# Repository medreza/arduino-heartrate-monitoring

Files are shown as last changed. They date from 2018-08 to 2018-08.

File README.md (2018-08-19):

# arduino-heartrate-monitoring

Heartrate monitoring based on photodiode sensor and Arduino. Uses Processing for user interface.

This was mini project for Electronics Instrumentation 2014 class in FMIPA Universitas Gadjah Mada. 

The video of this project can be seen on:
https://www.youtube.com/watch?v=Lp79tmzNe8U

### Some pics
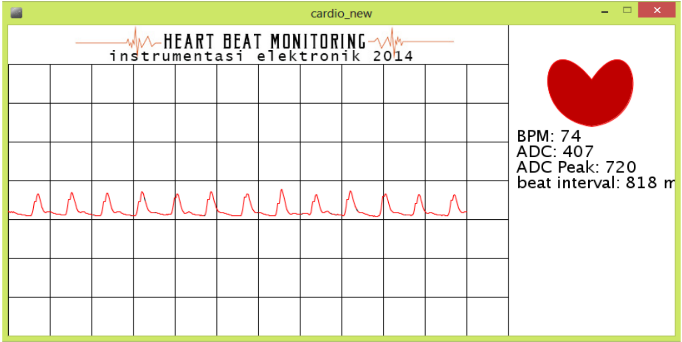
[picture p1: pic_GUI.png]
User interface using Processing IDE


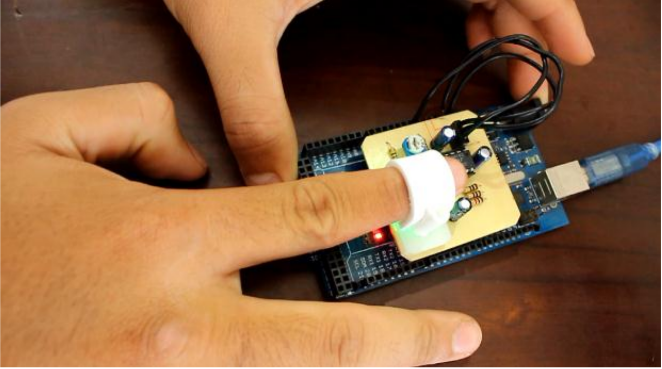
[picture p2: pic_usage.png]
Arduino with photodiode sensor


### Credit goes to team members
- Aditya Riska Putra
- Ahmed Reza Rafsanzani
- Ryan Eko Saputro
- Zainul Anam

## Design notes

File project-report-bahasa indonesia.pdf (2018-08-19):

## LAPORAN FINAL PROJECT

PENGUKURAN DETAK JANTUNG MENGGUNAKAN ARDUINO DAN

PROCESSING IDE

Mata Kuliah Instrumentasi Elektronik

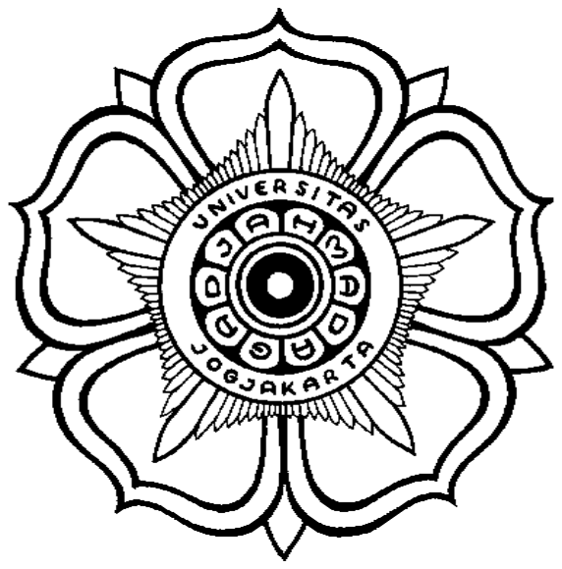
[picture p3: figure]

Disusun oleh:

ADITYA RISKA PUTRA | (12/331108/PA/14450)
AHMED REZA RAFSANZANI | (12/334832/PA/15030)
RYAN EKO SAPUTRO | (12/331380/PA/14638)
ZAINUL ANAM | (12/331361/PA/14624)

PROGRAM STUDI ELEKTRONIKA DAN INSTRUMENTASI

JURUSAN ILMU KOMPUTER DAN ELEKTRONIKA

FAKULTAS MATEMATIKA DAN ILMU PENGETAHUAN ALAM

UNIVERSITAS GADJAH MADA

YOGYAKARTA

2014

DAFTAR ISI

BAB I PENDAHULUAN

### 1.1 Latar Belakang

Instrumentasi biomedis adalah perangkat yang dapat digunakan untuk

mengukur besaran biologis atau medis dan memberikan hasil kuantitatif maupun

kualitatif. Instrumentasi medis ini berkaitan dengan perangkat medis yakni peralatan

yang digunakan dalam pemahaman, penanganan akses, dan pengobatan pada

manusia.

Perkembangan instrumentasi medis ini dapat dilihat dari perkembangan

perangkat medis. Stetoskop, alat medis pertama dari jenis sendiri yang diciptakan

oleh Laennec dokter Prancis. Pada tahun 1997, bahkan di komputer tomografi sudah

ada. Selama beberapa tahun ini, kedokteran telah memiliki ratusan perangkat

biomedis yang tersedia. Terobosan besar muncul ketika EKG diciptakan oleh para

ilmuwan Belanda pada tahun 1930. Hal tersebut adalah langkah pertama menuju

modernisasi Instrumentasi medis.

Hingga saat ini, perkembangan teknologi dan ilmu pengetahuan, tak

terkecuali dalam bidang medis, maju dengan cukup pesat. Salah satu perangkat

instrumentasi biomedis yang berkembang ialah pengukuran aktivitas jantung. Dalam

dunia kedokteran, pengukuran denyut jantung adalah hal yang sangat penting.

Pengukuran denyut jantung mengacu pada berapa jumlah waktu yang dibutuhkan

detak jantung persatuan waktu, yaitu beats per minute (bpm). Pada orang dewasa

yang sehat, saat sedang istirahat maka denyut jantung yang normal adalah sekitar 60-

100 denyut per menit (bpm). Saat ini, cara memonitoring aktivitas jantung yang

paling populer adalah dengan menggunakan Elektrokardiogram (EKG). EKG adalah

suatu sinyal yang dihasilkan oleh aktivitas listrik otot jantung. EKG merupakan

rekaman informasi kondisi jantung yang diambil dengan memasang elektroda pada

badan. Rekaman EKG ini digunakan secara luas oleh dokter ahli maupun rumah sakit

di seluruh dunia untuk menentukan kondisi jantung dari pasien.

Akan tetapi, EKG merupakan peralatan yang relatif mahal dan kurang bersifat

portable. Dalam penggunaan rumah tangga, EKG tidaklah lazim digunakan. Pada

penggunaan rumah tangga, seringkali pengukuran detak jantung menggunakan indra

pendengaran dengan menggunakan stetoskop. Melalui pendengaran yang baik banyak

informasi dapat diperoleh dari suara jantung. Suara jantung dapat didengar melalui

stetoskop oleh karena ada vibrasi pada jantung dan pembuluh darah besar. Biasanya

buka tutupnya valvula/katub jantung akan terdengar suara, demikian pula dapat

didengar aliran turbulensi pada saat-saat tertentu. Namun, penggunaan stetoskop pun

terkadang sukar untuk menentukan denyut jantung apabila terganggu oleh suara

bising. Dibutuhkan suatu alat yang mudah digunakan dalam kegiatan rumah tangga

dan lebih akurat daripada stetoskop. Dengan demikian, masyarakat dapat mengukur

detak jantung mereka secara efektif dan efisien dengan biaya yang terjangkau, serta

bersifat relatif mudah untuk dibangun dalam skala rumah tangga (do-it-yourself).

Terlebih lagi, saat ini sudah lazim beredar berbagai macam komponen-komponen dan

modul elektronika yang relatif mudah didapat dengan harga yang terjangkau daya beli

masyarakat.

### 1.2 Permasalahan

Permasalahan dalam penelitian ini ialah bagaimana membuat sistem

pengukuran detak jantung yang efektif dan efisien menggunakan mikrokontroler

Arduino, Processing IDE, dan bahan-bahan yang dapat dijangkau dalam kegiatan

sehari-hari atau dalam skala rumah tangga.

### 1.3 Tujuan Penelitian

Adapun tujuan dari penelitian ini adalah sebagai berikut.

1. Mambangun instrumen pengukuran detak jantung dengan berbasiskan

mikrokontroler Arduino dan Processing IDE.

2. Mambangun instrumen pengukuran detak jantung yang mudah dibuat

dalam skala penggunaan rumah tangga.

3. Memperkenalkan perangkat instrumentasi medis ke masyarakat.

### 1.4 Manfaat Penelitian

Sedangkan, manfaat yang diharapkan dapat terwujud dari penelitian ini adalah

sebagai berikut.

1. Masyarakat dapat dengan mudah mengukur detak jantung dengan alat yang

memiliki harga terjangkau dan dapat dibuat sendiri.

2. Memasyarakatkan aplikasi elektronika dalam perangkat instrumentasi

medis.

3. Meningkatkan kesadaran dan dukungan terhadap upaya pemerintah dalam

hal kesehatan jantung di Indonesia.

BAB II LANDASAN TEORI DAN TINJAUAN PUSTAKA

### 2.1 Palpasi

Palpasi berarti mengukur denyut nadi. Saat mengukur denyut nadi seorang

herbalis harus memusatkan perhatian dengan seksama. Menggunakan ujung jari

telunjuk, jari tengah, dan jari manis, untuk merasakan denyut nadi pasien dengan

meletakkan jari-jari di atas nadi radial (jari) pada pergelangan tangan pesakit.

Pada fase ini, cara merasakan denyut nadi digantikan oleh intensitas cahaya

yang ditangkap oleh fotodioda.

### 2.2 Fotodioda

Fotodioda adalah jenis dioda yang berfungsi mendeteksi cahaya. Berbeda

dengan diode biasa, komponen elektronika ini akan mengubah cahaya menjadi arus

listrik. Cahaya yang dapat dideteksi oleh diode foto ini mulai dari cahaya infra merah,

cahaya tampak, ultra ungu sampai dengan sinar-X. Aplikasi dioda foto mulai dari

penghitung kendaraan di jalan umum secara otomatis, pengukur cahaya pada kamera

serta beberapa peralatan di bidang medis.

### 2.3 Inframerah

Inframerah adalah radiasi elektromagnetik dari panjang gelombang lebih

panjang dari cahaya tampak, tetapi lebih pendek dari radiasi gelombang radio.

Namanya berarti "bawah merah" (dari bahasa Latin infra, "bawah"), merah

merupakan warna dari cahaya tampak dengan gelombang terpanjang. Radiasi inframerah memiliki jangkauan tiga "order" dan memiliki panjang gelombang antara

700 nm dan 1 mm. Inframerah ditemukan secara tidak sengaja oleh Sir William

Herschell, astronom kerajaan Inggris ketika ia sedang mengadakan penelitian mencari

bahan penyaring optis yang akan digunakan untuk mengurangi kecerahan gambar

matahari pada teleskop tata surya.

Inframerah digunakan sebagai sumber cahaya utama yang akan menerangi

dan menembus denyut nadi agar perubahan instensitas cahaya dapat dilihat secara

signifikan oleh sensor fotodioda.

### 2.4 Tinjauan Pustaka

Darah mengalir melalui sistem pembuluh tertutup karena ada perbedaan

tekanan atau gradien tekanan antara ventrikel kiri dan atrium kanan (Ethel, 2003:

238). Pengaliran darah dari jantung ini juga menirukan detak jantung sehingga

disebut sebagai denyut nadi. Denyut nadi adalah denyutan arteri dari gelombang

darah yang mengalir melalui pembuluh darah sebagai akibat dari denyutan jantung.

Denyut nadi sering diambil di pergelangan tangan untuk memperkirakan denyut

jantung. Denyut nadi dapat dengan mudah diperiksa dengan jari tangan atau dengan

cara palpasi, disamping itu dapat pula ditentukan dengan menggunakan peralatan

elektronik yang sederhana maupun yang modern. Pemeriksaan denyut nadi dan

pengukuran tekanan darah merupakan faktor yang dapat dipakai sebagai indikator

untuk menilai sistem kardiovaskuler.

Tersedianya perangkat elektronik yang dapat merasakan fenomena fisis tentu

dapat digunakan dalam hal pengukuran juga, dalam hal ini pengukuran detak jantung.

Perubahan detak jantung pada pembuluh nadi memiliki karakteristik perubahan

intensitas cahaya yang dapat ditangkap dengan menggunakan fotodioda. Tegangan

pada fotodioda kemudian akan berubah-ubah sesuai detak jantung atau aliran darah

yang mengalir.

Data yang didapat kemudian dapat diolah dengan mikrokontroler platform

Arduino guna memungkinkan perluasan potensi pemanfaatan data yang lebih jauh

lagi.

BAB III METODE PENELITIAN

### 3.1 Jenis Penelitian

Jenis penelitian ini merupakan penelitian terapan. Penelitian terapan atau

applied research dilakukan berkenaan dengan kenyataan-kenyataan praktis,

penerapan, dan pengembangan ilmu pengetahuan yang dihasilkan oleh penelitian

dasar dalam kehidupan nyata. Penelitian terapan berfungsi untuk mencari solusi

tentang masalah-masalah tertentu. Tujuan utama penelitian terapan adalah pemecahan

masalah sehingga hasil penelitian dapat dimanfaatkan untuk kepentingan manusia

baik secara individu atau kelompok maupun untuk keperluan industri atau politik dan

bukan untuk wawasan keilmuan semata (Sukardi, 2003).

Pada penelitian ini, peneliti melakukan eskperimen didasarkan atas kajian

teoritis mengenai instrumentasi dalam bidang biomedis.

### 3.2 Metode Pengumpulan Data

Untuk mempermudah penelitian ini peneliti menggunakan beberapa metode

pengumpulan data, diantaranya adalah sebagai berikut.

3.2.1 Observasi

Menurut (Guba dan Lincoln, 1981: 191-193), observasi hakikatnya

merupakan kegiatan dengan menggunakan pancaindera, dapat berupa

penglihatan, penciuman, pendengaran, untuk memperoleh informasi yang

diperlukan untuk menjawab masalah penelitian. Hasil observasi berupa

aktivitas, kejadian, peristiwa, objek, kondisi atau suasana tertentu, dan perasaan emosi seseorang. Observasi dilakukan untuk memperoleh

gambaran riil suatu peristiwa atau kejadian untuk menjawab pertanyaan

penelitian.

Observasi dilakukan dengan cara mengamati perubahan yang terjadi

pada respon dari objek penelitian. Data yang didapat pada perubahan respon

tersebut kemudian dibandingkan dengan keadaan sebenarnya.

Dalam penelitian ini, respon detak jantung dari objek penelitianlah

yang akan diamati dan dibandingkan dengan keadaan sebenarnya. Hasil

penelitian akan semakin baik apabila data yang didapat dari produk

penelitian mendekati dengan data keadaan yang sesungguhnya.

3.2.2 Kalibrasi dan Uji Coba Alat

Menurut | ISO/IEC | Guide | 17025:2005 | dan | Vocabulary | of

International Metrology (VIM), kalibrasi adalah serangkaian kegiatan yang

membentuk hubungan antara nilai yang ditunjukkan oleh instrumen ukur

atau sistem pengukuran, atau nilai yang diwakili oleh bahan ukur, dengan

nilai-nilai yang sudah diketahui yang berkaitan dari besaran yang diukur

dalam kondisi tertentu. Pada penelitian ini, kalibrasi dilakukan dengan

membandingkan hasi l pengukuran alat yang dibuat dengan pengukuran

detak jantung yang biasa digunakan dalam dunia medis, yaitu stetoskop

dan/atau pemeriksaan denyut nadi dengan menggunakan tangan.

Uji coba alat dilakukan menjalankan sistem secara keseluruhan.

Sistem yang dibuat adalah jawaban dari permasalahan yang telah dikemukakan, yaitu alat pengukur detak jantung dengan Arduino dan

Processing IDE.

BAB IV HASIL PENELITIAN DAN PEMBAHASAN

### 4.1 Perancangan Alat

Prinsip utama kerja alat adalah dengan mendeteksi detak jantung dengan

memanfaatkan karakteristik keja mekanis jantung. Secara spesifik, ketika jantung

bekerja dengan memompa darah mengalir keseluruh tubuh atau kembali ke jantung,

terjadi perubahan ukuran pembuluh darah pada bagian tubuh. Perubahan ukuran

pembuluh darah pada periode waktu detak dapat mewakili irama denyut jantung

dalam tubuh. Fenomena ini sebenarnya dapat dirasakan oleh semua orang ketika

dalam kondisi rileks, terutama pembuluh darah yang terletak dekat dengan

permukaan kulit. Fenomena ini disebut juga sebagai pergerakan makroskopik

pembuluh darah.

Perancangan sistem alat dilakukan sesuai dengan kebutuhan komponen-

komponen elektronika yang dapat mengukur fenomena denyut perubahan lebar

pembuluh darah pada jari manusia. Pada sistem ini digunakan 4 (empat) komponen

utama, yakni sensor (probe) sebagai input sistem, rangkaian pengkondisi sinyal,

mikrokontroler sebagai pengolah data, dan software Processing IDE sebagai

penampil grafik sinyal denyut jantung yang dilengkapi dengan data hasil perhitungan

beats per minute (BPM). Adapun alat dan bahan yang dibutuhkan dalam perancangan

serta tahapan-tahapan rancang bangun sistem adalah sebagai berikut.

4.1.1 Alat dan Bahan

- Arduino development board | 1 buah

- Solder | 1 buah
- Tang potong | 1 buah
- Bor PCB dan mata bor 0.8 mm | 1 buah
- Tenol | 1 meter
- Power Amplifier LM386 | 1 buah
- Photo diode 5 mm | 1 buah
- LED superbright hijau 5 mm | 1 buah
- Resistor 150 Ω | 1 buah
- Potensiometer 10kΩ | 1 buah
- Resistor 5kΩ | 1 buah
- Resistor 100 Ω | 2 buah
- Resistor 1kΩ | 1 buah
- Kapasitor 1 uf | 2 buah
- Kapasitor 100 uf | 2 buah
- Kabel jumper | secukupnya
- PCB fiber | 1 lembar 5x5 cm
- Black housing | 2 buah
- Kabel USB printer | 1 buah
- Buzzer | 2 buah
- Spacer | 1 buah

4.1.2 Tahapan Rancang Bangun Alat

1. Perancangan PCB berdasarkan skema rangkaian,
2. pemasangan komponen-komponen elektronika pada rangkaian,

3. modul-modul | rangkaian | sensor, | amplifier, | mikrokontroler | saling

dihubungkan dengan Arduino IDE dan software Processing IDE pada

komputer melalui komunikasi serial via port USB ,

4. pemrograman mikrokontroler dan antarmuka pada Processing,
5. kalibrasi dan uji coba alat.

### 4.2 Blok Diagram Sistem

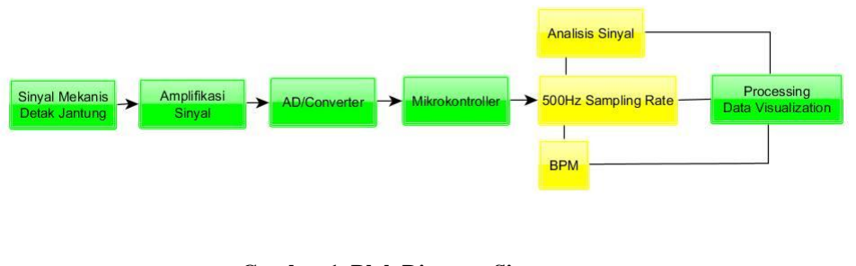
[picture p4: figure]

Gambar 1. Blok Diagram Sistem

### 4.3 Skema Rangkaian

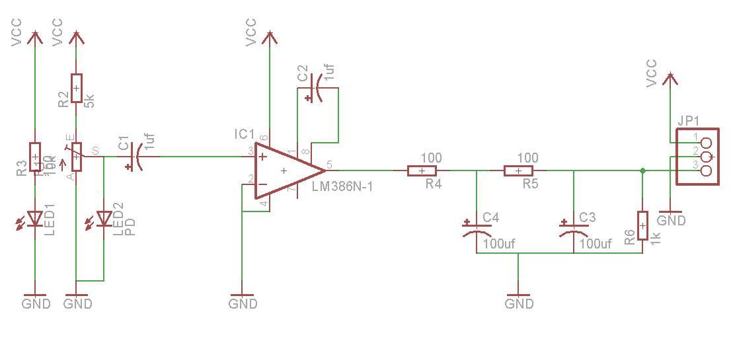
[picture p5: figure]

Gambar 2. Skema Rangkaian Sistem

### 4.4 Listing Program

Pemrograman pada sistem ini dibutuhkan pada mikrokontroler Arduino dan

antarmuka pengguna pada software Processing. Listing program keduanya adalah

sebagai berikut.

4.4.1 Program pada Mikrokontroler Arduino

// PROGRAM UTAMA

int signalPin = 0;
int ledPin = 13;
int buzzPin = 49;
volatile int BPM;
volatile int Signal;
volatile int beatInterval = 450; volatile boolean pulseArea = false; volatile boolean findBeat = false;

void setup(){
pinMode(ledPin,OUTPUT);
pinMode(buzzPin,OUTPUT);
Serial.begin(115200);
interruptSetup();
}

void loop(){
sendDataToProcessing('S', Signal);
if (findBeat == true){
sendDataToProcessing('B',BPM); sendDataToProcessing('Q',beatInterval); findBeat = false;
}
delay(20);
}

void sendDataToProcessing(char symbol, int data ){ Serial.print(symbol);
Serial.println(data);
}

//PROGRAM DENGAN INTERRUPT

volatile int temp[10];
volatile unsigned long sampleCounter = 0; volatile unsigned long lastBeatTime = 0; volatile int Max =415;
volatile int Min = 415;
volatile int thres = 415;
volatile int Amp = 100;
volatile boolean firstBeat = true; volatile boolean secondBeat = true;

void interruptSetup(){
TCCR2A = 0x02;
TCCR2B = 0x06;
OCR2A = 0X7C;
TIMSK2 = 0x02;
sei();
}

ISR(TIMER2_COMPA_vect){
cli();
Signal = analogRead(signalPin); sampleCounter += 2;
int N = sampleCounter - lastBeatTime;

if(Signal < thres && N > (beatInterval/5)*3){ if (Signal < Min){
Min = Signal;
}
}

if(Signal > thres && Signal > Max){ Max = Signal;
}

if (N > 270){
if ( (Signal > thres) && (pulseArea == false) && (N > (beatInterval/5)*3) ){
pulseArea = true;
digitalWrite(ledPin,HIGH); digitalWrite(buzzPin,HIGH);
beatInterval = sampleCounter - lastBeatTime; lastBeatTime = sampleCounter;

if(firstBeat){
firstBeat = false;
return;
}
if(secondBeat){
secondBeat = false;
for(int i=0; i<=9; i++){
temp[i] = beatInterval;
}
}
word runningTotal = 0;
for(int i=0; i<=8; i++){
temp[i] = temp[i+1];
runningTotal += temp[i];
}

temp[9] = beatInterval;
runningTotal += temp[9];
runningTotal /= 10;
BPM = 60000/runningTotal;
findBeat = true;
}
}

if (Signal < thres && pulseArea == true){ digitalWrite(ledPin,LOW);
digitalWrite(buzzPin,LOW); pulseArea = false;
Amp = Max - Min;
thres = Amp/2 + Min;
Max = thres;
Min = thres;
}

if (N > 2500){
thres = 415;
Max = 415;
Min = 415;
lastBeatTime = sampleCounter; firstBeat = true;
secondBeat = true;
}

sei();
}

4.4.2 Program pada Processing IDE

import processing.serial.*; Serial myPort;
int xPos = 1;
float oldHeartrateHeight = 0; int videoScale = 50;
int cols, rows;
int peak = 0;
float heartanim;
float heartsize;
int BPM;
int IBI;
int currentHeartrate;
boolean beat;
PImage img;
PImage imgbg;

void setup () {
img = loadImage("bg1.jpg"); imgbg = loadImage("bg2.jpg"); size(820, 400);
frameRate(60);
cols = 600/videoScale;
rows = height/videoScale;
int runonce = 0;
myPort = new Serial(this, "COM1", 115200); textSize(20);

background(255);

for (int i = 0; i < cols; i++) { for (int j = 0; j < rows; j++) {

int x = i*videoScale;
int y = j*videoScale;
noFill();
stroke(1);

rect(x,y,videoScale,videoScale); noStroke();
}
}

}

void grid(){
for (int i = 0; i < cols; i++) { for (int j = 0; j < rows; j++) {

int x = i*videoScale;
int y = j*videoScale;
noFill();
stroke(1);

rect(x,y,videoScale,videoScale); noStroke();
}
}
}

void draw () {
noStroke();

fill(255,255,255);
rect(602,0,198,400);
noFill();
fill(0,255,0);
image(img, 0, 0);
noFill();

fill(250,0,0);
stroke(250,0,0);
heartsize = map(heartanim,0.0,height,150.0,255.0); if (heartsize >=150 && heartsize <=255){ fill(heartsize,0,0);
}
beginShape();
smooth();
bezier(width-100,70, width-50,-10, width-20,120, width-100,130);
bezier(width-100,70, width-160,-10, width-180,120, width-100,130);
strokeWeight(1);
endShape();
noStroke();
fill(0,0,0);
text("ADC Peak: " + peak,610,190); text("ADC: " + currentHeartrate,610,170);

if (beat == true) {
text("BPM: " + BPM,610,150); } else {
text("BPM: 0",610,150);
}
text("beat interval: " + IBI + " ms",610,210); noFill();
}

void serialEvent (Serial myPort) {

String inString = myPort.readStringUntil('\n');

if (inString != null) {

inString = trim(inString);

println(inString);
if (inString.charAt(0) == 'S'){ inString = inString.substring(1); currentHeartrate = int(inString); }
if (inString.charAt(0) == 'B'){ inString = inString.substring(1); BPM = int(inString);
beat = true;

}
if (inString.charAt(0) == 'Q'){ inString = inString.substring(1); IBI = int(inString);
}

if (currentHeartrate >= peak){ peak = currentHeartrate;
}

float heartrateHeight = map(currentHeartrate, 300, 600, 0, height);
heartanim = heartrateHeight;
stroke(255,0,0);
strokeWeight(1);
line(xPos - 1, height - oldHeartrateHeight, xPos, height -heartrateHeight);
oldHeartrateHeight = heartrateHeight;
smooth();
noStroke();

if (xPos >= 600) {
xPos = 0;
background(255);
grid();
} else {

xPos++;

}
}
}

### 4.5 Mekanisme Kerja Alat

Prinsip utama alat yang dikembangkan ini adalah dengan mendeteksi

perubahan ukuran dari pembuluh darah yang dapat mewakili irama detak jantung.

Probe sensor dari alat yang dikembangkan ini terdiri dari LED superbright sebagai

sumber cahaya dan fotodioda sebagai sensor pendeteksi cahaya. Perubahan ukuran

pembuluh darah sebagai akibat aktivitas kerja jantung akan mempengaruhi perubahan

intensitas cahaya yang diterima oleh sensor cahaya.

Proses alur kerja alat yang dikembangkan ini adalah bahwa perubahan ukuran

pembuluh darah dideteksi oleh sensor cahaya sebaga probe utama. Kemudian sinyal

output sensor dikuatkan menggunakan rangkaian amplifer untuk memperkuat sinyal

dan mengkodisikan sinyal agar dapat diolah oleh mikrokontroler. Sinyal hasil

penguatan amplifier kemudian dihubungkan dengan port analog mikrokontroler

untuk menjalani proses konversi sinyal kedalam bentuk sinyal digital oleh modul

ADC. Pada mikrokontroler, sinyal diolah dan dianalisis untuk diambil beberapa data

mengenai puncak gelombang, palung gelombang, jarak antar detak, dan nilai

pendekatan jumlah detak jantung permenit atau yang lazim disebut sebagai beats per

minute (BPM). Hasil pemrosesan data oleh mirokontroler tersebut kemudian dikirimkan ke software Processing IDE melalui komunikasi serial sebagai penampil

data hasil dan bentuk gelombang secara visual.

Probe sensor detak jantung tersusun dari fotodioda dan LED superbright.

Konfigurasi susunan sensor pada skematik rangkaian ditunjukkan oleh Gambar 1.

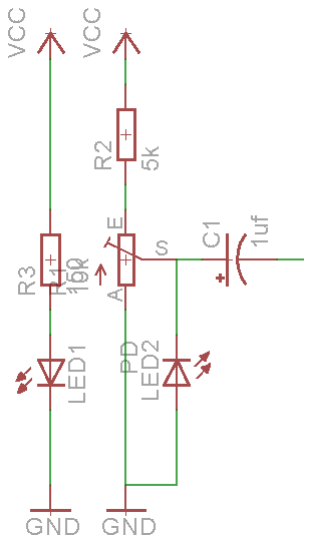
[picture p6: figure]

Gambar 3. Rangkaian Sensor dengan Pembagi Tegangan

Rangkaian pada Gambar 1 merupakan rangkaian yang menangani proses

pembacaan perubahan ukuran pembuluh darah. Konfigurasi rangkaian yang

digunakan adalah konfigurasi pembagi tegangan dengan salah satu resistor adalah

fotodioda. Fotodioda bertindak sebagai resistor dengan konfigurasi bias mundur.

Pada konfigurasi bias mundur, rangkaian pembagi tegangan seolah-olah berada pada

kedudukan rangkaian terbuka (resistansi fotodioda tinggi), sehingga tidak ada sinyal

yang diteruskan menuju ke dalam rangkaian penguat (amplifier). Ketika cahaya

dengan intensitas tertentu diterima oleh fotodioda, maka fotodioda mengalami

kebocoran arus, sehingga arus akan mengalir dari katoda menuju anoda dan

menyebabkan sinyal pembacaan aktivitas detak jantung menuju ke rangkaian penguat

sinyal. Pada rangkaian di atas terdapat potentiometer 10K Ω dan kapasitor 1uf.

Peotensiometer berungsi untuk memanipulasi resistansi pada rangkaian pembagi

tegangan sehingga berdampak pada berubahnya sensitifitas sensor. Kapasitor pada rangkaian tersebut (sebelum menuju pada rangkaian penguat sinyal) berfungsi

sebagai pembentuk sinyal gelombang yang merepresentasikan detak jantung.

berfungsi sebagai pembentuk sinyal gelombang yang merepresentasikan detak

jantung.

Setelah sinyal detak dideteksi oleh rangkaian konfigurasi pembagi tegangan,

kemudian sinyal hasil pendeteksian tersebut dikuatkan oleh rangkaian penguat

(amplifier). Rangkaian penguat yang dipilih adalah dengan IC LM386. LM386

merupakan audio amplifier yang memiliki penguatan (gain) 20 kali hingga 200 kali

pada chip tunggal. Berikut merupakan skema sub rangkaian penguat sinyal.

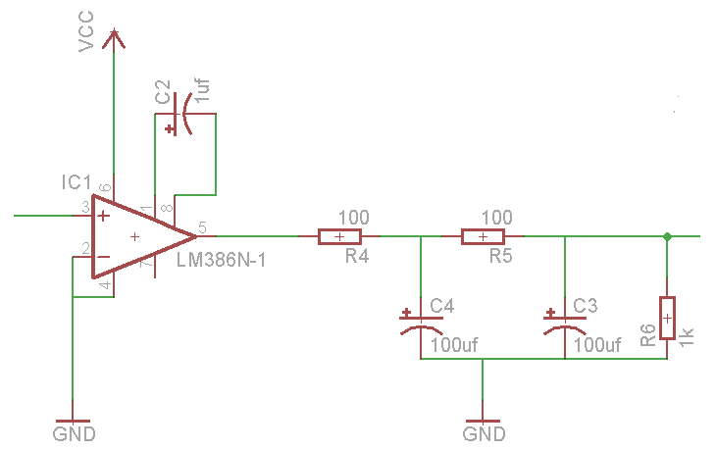
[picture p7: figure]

Gambar 4. Rangkaian Amplifier dan Low Pass Filter

IC LM386 dipilih sebagai penguat sinyal karena rangkaan penguatan yang mudah dan

sederhana. Hal ini dapat dicapai karena proses penguatan pada LM386 hanya diatur

melalui pin 1 dan 8. Untuk mendapatkan nilai gain 20, maka antara pin 1 dan 8 tidak

dihungungkan pada rangkaian apapun. Sedangkan untuk mendapatkan peguatan

maksimal dengan gain 200, maka antara pin 1 dan 8 dipasangkan kapasitor sebagai

rangkaian bypass hambatan pin 1 dan 8. Untuk mendapatkan penguatan anatara 20

hingga 200, pin 1 dan 8 dapat dihungungakn dengan resistor yang memiliki resistansi

tertentu. Berikut ini adalah datasheet dan persamaan untuk menghitung besar gain

pada LM386.

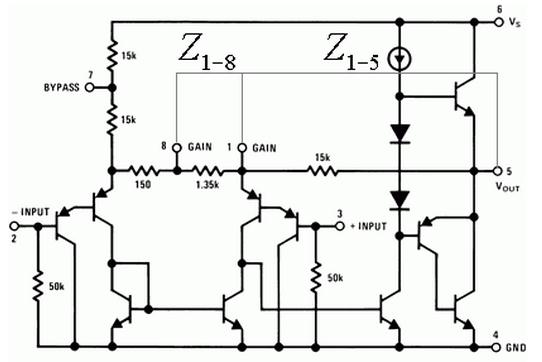
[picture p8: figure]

Gambar 5. Datasheet LM386

Untuk dapat menghitung gain pada amplifier LM386 dapat digunakan persamaan

sebagai berikut.

Keterangan :

Sehingga untuk mendapatkan gain maksimal seperti pada rangkaian kami, maka pin 1

dan 8 dihubungkan dengan kapasitor untuk mem-bypass hambatan pin 1 dan 8

sebesar 1.35 kΩ.

Sinyal output hasil penguatan kemudian masuk pada rangkaian filter.

Rangkaian filter yang dipilih adalah konfigurasi low pass filter. Pada rangkian

gambar 2, dapat dilihat terdapat konfigurasi cascaded low pass filter. Penggunaan

lowpass filter ini bertujuan untuk membuang sinyal pengganggu yang menyebabkan

sinyal detak jantung tidak teramati dengan baik. Frekuensi gelombang pada pin 5

(output LM386) sangat tinggi dan menyebabkan sinyal detak jantung tidak terbaca,

sehingga low pass filter ini dipilih sebagai alternatif untuk membuang sinyal noise

hasil penguatan.

Pada rangkaian low pass filter dipilih resistansi sebesar 100 Ω dan kapasitor

sebesar 100uf. Rangkaian tersebut akan memberikan cut off frekuensi yang dapat

dihitung dengan persamaan beikut.

Persamaan di atas hanya digunakan untuk menghitung mode tunggal. Untuk model

filter yang tersusun bertingkat dapat menggunakan persamaan berikut.

√

Karena pada rangkaian diatas menggunakan resistansi dan kapasitansi yang bernilai

sama, maka penggunaan kedua rumus tersebut akan menghasilkan nilai yang sama.

Dari hasil perhitungan didapatkan nilai cut off frekuensi sebesar 15.9 Hz. Hal ini

memiliki pengertian bahwa sinyal penguatan yang memiliki frekuensi diatas

frekuensi cut off maka sinyal tersebut akan dilemahkan. Tujuan pembuatan low pass

bersusun pada rangkaian diatas adalah untuk tujuan pengembangan alat kedepan

dengan tujuan mendapatkan hasil maksimal.

Setelah melalui proses penguatan dan filter, kemudian sinyal hasil

pengkondisian masuk kedalam port analog mirokontroler untuk dilakukan proses

digitalisasi oleh modul ADC. Proses digitalisasi ini bertujuan agar sinyal input dapat

dimengerti dan diolah oleh mikrokontroler,. Hal ini dilakukan karena mikrokontroler

hanya mampu memahami beroperasi menggunakan prinsip sinyal digital.

Pada mikrokontroler, sinyal hasil pengujian akan dilakukan sampling selama

2ms atau pada frekuensi 500Hz. Nilai ini dipilih kaena sinyal ECG berada pada

rentang 0-500Hz. Proses sampling sinyal pada mikrokontroler menggunakan mode

interrupt. Mode interrupt yang digunakan adalah dengan membandingkan nilai

counter TIMER2 dengan nilai OCR2A (CTC mode). Berikut ini adalah kalkulasi pada

proses inisialisasi timer yang digunakan sebagai kolom waktu pemrosesan sinyal

input:

- Clock arduino mega menggunakan 16MHz sehingga waktu perubahan 1 clock

adalah 1/16000000 = 0,0625us (waktu yang dibutuhkan clock melakukan satu

kali detak).

- Arduino mega memiliki timer 8 bit ---> 0 sampai 255
- 0,0625uS*256 = 1,6x10⁻⁵ merupakan waktu yang dibutuhkan timer mencapai

nilai maksimum (overflow).

- Menggunakan prescaler 256 untuk memperlambat clock timer maka 256*1,6x10⁻⁵
= 4,096 ms. Nilai waktu tersebut direpresentasikan dengan nilai

counting 0-255 atau dengan kata lain perubahan nilai counter timer dari 0

hingga 255 membutuhkan waktu 4,09d ms. Sehingga untuk waktu 2ms

(sebagai waktu sampling) maka counter timer hanya berakhir pada nilai 124.
- Periode sampling 2ms = 2x10⁻³
didapatkan dengan melakukan perbandingan

nilai ORC2A dengan TIMSK2 untuk mencapai counter 124.

Ilustrasi tersebut merupakan ilustrasi mengenai pemilihan nilai dan setup interrupt

pada arduino untuk melakukan proses sampling sinyal.

Pemrosesan sinyal pada sistem ini bersifat dinamis yang berarti mampu

beradaptasi pada perubahan nilai berapapun dari pendeteksian detak jantung. Sistem

dapat membedakan siyal puncak maksimal dan sinyal puncak minimal sebagai modal

analisis detak jantung. Sistem juga dapat mendeteksi jarak waktu antar detak dan

dapat melakukan pendekatan perhitungan nilai BPM (beats per minute) pada proses

pengujian dengan cepat tanpa memerlukan waktu 1 (satu) menit proses sampling

secara penuh.

Hasil pengolahan sinyal kemudian dikirimkan ke software Processing pada

komputer melalui komunikasi serial untuk memvisualisasikan data hasil analisis.

Berikut merupakan gambar tampilan software Processing yang dikembangkan.

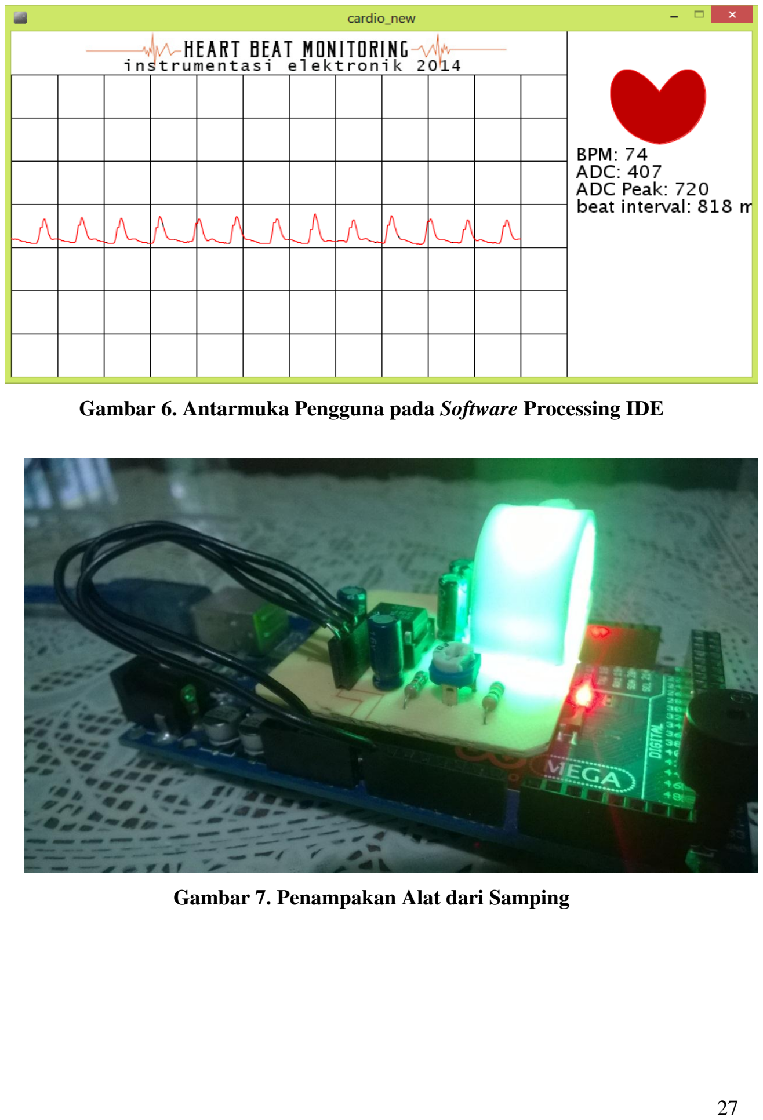
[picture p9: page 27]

Gambar 6. Antarmuka Pengguna pada Software Processing IDE

Gambar 7. Penampakan Alat dari Samping

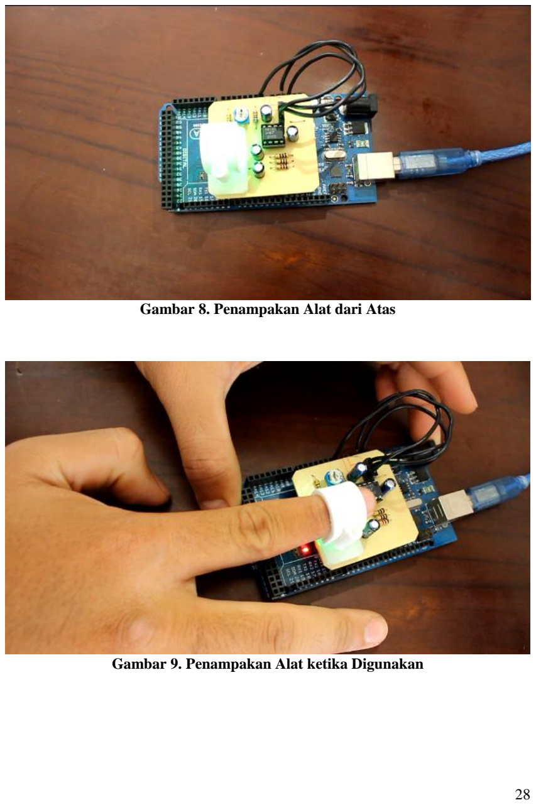
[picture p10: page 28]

Gambar 8. Penampakan Alat dari Atas

Gambar 9. Penampakan Alat ketika Digunakan

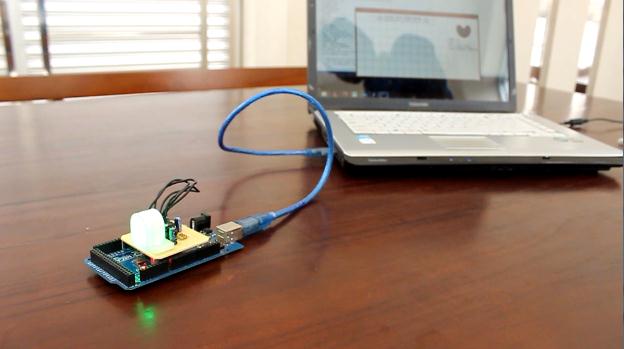
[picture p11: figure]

Gambar 10. Implementasi Sistem secara Keseluruhan

BAB V KESIMPULAN

### 5.1 Kesimpulan

Pengukuran detak jantung menggunakan Arduino dan Processing IDE dapat

dibuat dengan perancangan alat yang dapat mengukur fenomena denyut perubahan

lebar pembuluh darah pada permukaan kulit manusia. Perubahan lebar pembuluh

darah tersebut dapat dideteksi dengan mengukur perubahan intensitas cahaya yang

mampu melewati pembuluh darah. Pada sistem ini digunakan 4 (empat) komponen

utama, yakni sensor (probe) sebagai input sistem berupa sumber cahaya dan

fotodioda, rangkaian pengkondisi sinyal, mikrokontroler sebagai pengolah data, dan

software Processing IDE sebagai penampil grafik sinyal denyut jantung yang

dilengkapi dengan data hasil perhitungan beats per minute (BPM).

DAFTAR PUSTAKA

Anonim. http://haekalherbal.wordpress.com/about/. Diakses 22 September 2014

Anonim. http://id.wikipedia.org/wiki/Inframerah. Diakses 22 September 2014.

Bungin, Burhan. 2001. Metode Penelitian Kualitatif. Jakarta: PT Raja Grafindo

Persada

Gabriel. J.F. 1996. Fisika Kedokteran. Jakarta: EGC.

Gitman, Yury, Joel Murphy. http://pulsesensor.myshopify.com/pages/code-and-

guide. Diakses 10 Oktober 2014.

James, Joyce. dkk. 2008. Prinsip-Prinsip Sains Untuk Keperawatan. Jakarta: Buku

Erlangga.

Khandpur, RS. 2003. Hand Book of Biomedical Instrumentation 2nd Edition. New

Delhi:Tata McGraw-Hill.

Sarwano, Jonathan. 2006. Metode Penelitian Kuantitatif & Kualitatif. Yogyakarta:

Graha Ilmu

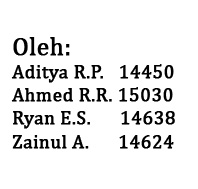
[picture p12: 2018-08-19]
heartrateGUI/bg2.jpg

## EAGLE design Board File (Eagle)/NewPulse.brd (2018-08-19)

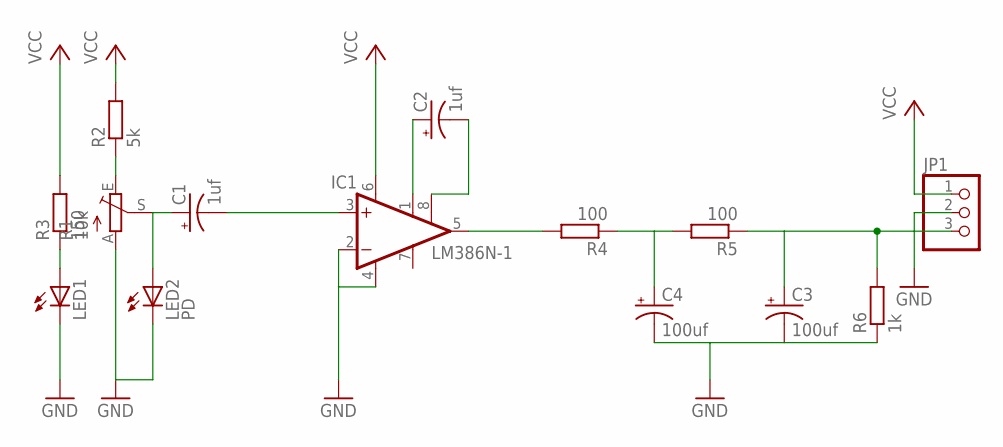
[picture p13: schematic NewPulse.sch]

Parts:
C1, C2: 1uf; E2-5
C3, C4: 100uf; E2-5
IC1: LM386N-1; DIL08
JP1: PINHD-1X3/90; 1X03/90
LED1: LED5MM
LED2: PD; LED5MM
R1: 10k; CA6V
R2: 5k; 0207/10
R3: 150; 0207/10
R4, R5: 100; 0207/10
R6: 1k; 0207/10

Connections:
GND: C3.-, C4.-, IC1.2 (-IN), IC1.4 (GND), JP1.2, LED1.K (C), LED2.K (C), R1.A, R6.1
unnamed: LED1.A, R3.1
unnamed: R1.E, R2.1
unnamed: C1.+, LED2.A, R1.S
unnamed: C1.-, IC1.3 (+IN)
unnamed: C2.+, IC1.1 (GAIN)
unnamed: C2.-, IC1.8 (GAIN)
unnamed: IC1.5 (OUT), R4.2
unnamed: C4.+, R4.1, R5.2
unnamed: C3.+, JP1.3, R5.1, R6.2
VCC: IC1.6 (VS), JP1.1, R2.2, R3.2

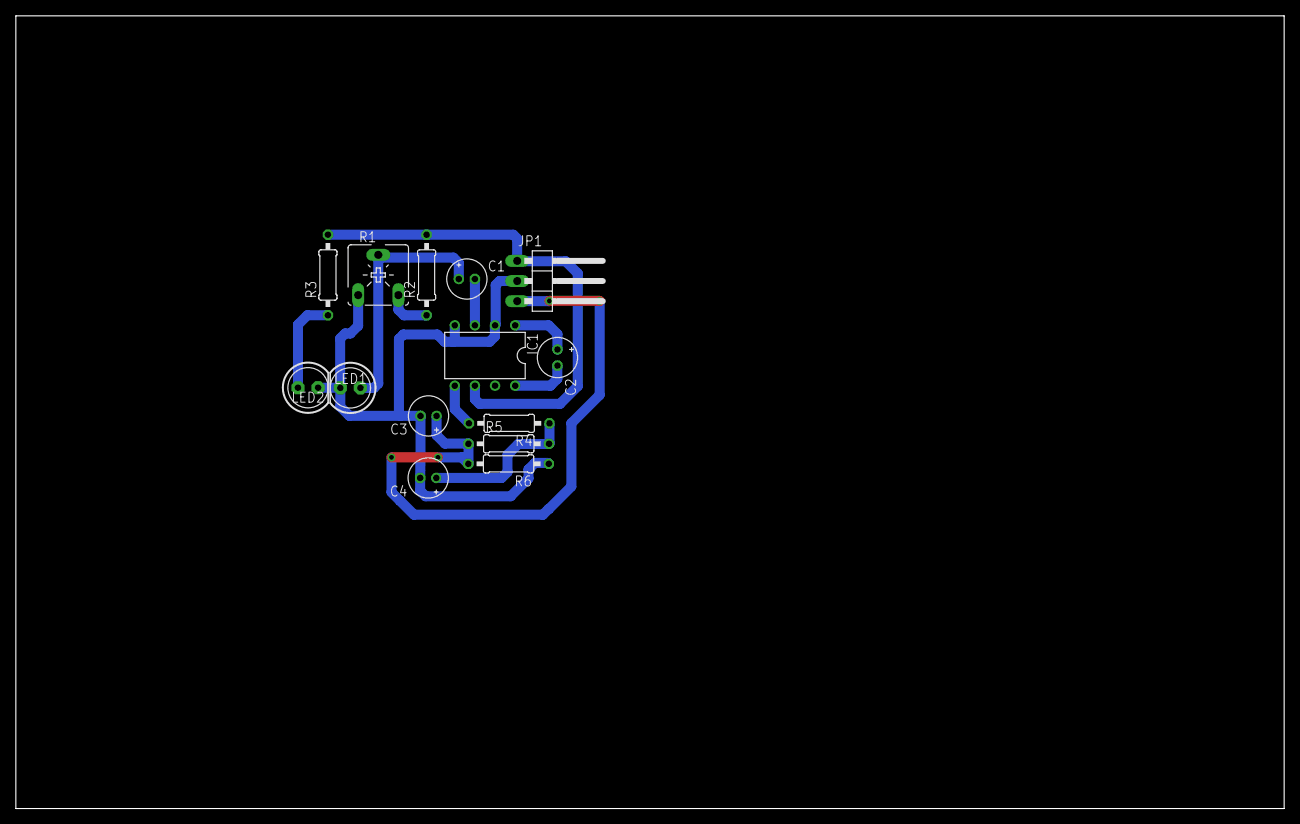
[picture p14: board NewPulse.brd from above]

Board: 2 copper layers, 160.0 x 100.0 mm, 14 parts (0 on the bottom side), 11 nets.

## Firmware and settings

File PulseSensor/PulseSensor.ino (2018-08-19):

//  VARIABLES
int signalPin = 0;       //  Input dari rangkaian penguat                
int ledPin = 13;         //  Pin led       
int buzzPin = 49;        //  Pin buzze                    
volatile int BPM;        //  Variabel volatil penyimpan nilai BPM          
volatile int Signal;     //  Variabel volatil penyimpan nilai ADC          
volatile int beatInterval = 450;    // dengan asumsi bahwa setiap detik(paling banyak) melakkan detak 220bpm sehingga 1 beat memakan waktu 0,27s atau 270mS (beat interval paling pendek) Hanya sebagai nilai awal!!!
volatile boolean pulseArea = false; // flag area detak     
volatile boolean findBeat = false;  // flag untuk meandakan bawa beat ditemukan     

void setup(){
  pinMode(ledPin,OUTPUT); // mode output pada pin
  pinMode(buzzPin,OUTPUT);// mode output pada pin           
  Serial.begin(115200);   // baud rate          
  interruptSetup();       // start up setting fungsi interupt         
}



void loop(){
  sendDataToProcessing('S', Signal);      // secara default mengirimkan data dengan header "S". Hali ini digunakan untuk visualisasi bentuk gelombang pada software processing    
  if (findBeat == true){                  // Jika detak ditemukan                                    
        sendDataToProcessing('B',BPM);    // data BPM akan disisipkan pada pengiriman data serial.  
        sendDataToProcessing('Q',beatInterval);  //data interval detak juga akan disisipkan
        findBeat = false;                 // reset flag                      
     }
  delay(20);                              // delay 
}


void sendDataToProcessing(char symbol, int data ){ //fungsi untuk mengemas data serial
    Serial.print(symbol);           //dengan hirari pengiriman simbol header diikuti nilai    
    Serial.println(data);                
  }

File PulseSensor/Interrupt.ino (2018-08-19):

volatile int temp[10];                          // menyimpan jarak antar detak dan melakukan rata-rata
volatile unsigned long sampleCounter = 0;       // untuk melakukan perhtungan waktu setiap interupt berjalan
volatile unsigned long lastBeatTime = 0;        // untuk menyimpan nilai waktu antar detak
volatile int Max =415;                          // digunakan untuk menemukan puncak gelombang
volatile int Min = 415;                         // digunakan untuk menemukan lembah gelombang
volatile int thres = 415;                       // batas nilai detak
volatile int Amp = 100;                         // digunakan untuk menyimpan amplitudo gelombang
volatile boolean firstBeat = true;              // flag
volatile boolean secondBeat = true;             // flag

//clock menggunakan 16MHz maka waktu perubahan 1 clock adalah 1/16000000 = 0,0625uS
//menggunakan timer 8 bit --->0 sampai 255
//0,0625uS*256 = 1,6 x10^-5 merupakan waktu yang dibutuhkan timer mencapai nilai maksimum (overflow)
//Menggunakan prescaler 256 untuk memperlambat clock timer maka 256*1,6x10^-5 = 4,096 mS direpresentasikan dengan nilai counting 0-255, untuk waktu 2mS maka counting hanya berakhir pada nilai 124
//Untuk sampling rate  = 500Hz maka periode adalah 1/500 = 2x10^-3s atau 2mS
//periode sampling 2mS = 2x10^-3 didapatkan dengan melakukan perbandingan nilai ORC2A dengan TIMSK2 untuk mencapai counter 124.


void interruptSetup(){  
  TCCR2A = 0x02;     // menonaktifkan PWM pin 3 dan 11 serta mengaktifkan mode CTC (mode inerupt perbandingan)
  TCCR2B = 0x06;     // memilih prescaler 256 (untuk memperlambat clock)
  OCR2A = 0X7C;      // memasukan nilai 124 pada register OCR2A (1/2 kapasitas counter unuk mencapai interupt 2ms)
  TIMSK2 = 0x02;     // mengaktifkan interup untuk membandingkan nilai antara TIMER2 dan ORC2A
  sei();             // global interupt      
} 
 

ISR(TIMER2_COMPA_vect){                                 // ISR ini akan dijalankan setiap 2ms atau ketika proses counting mencapai nilai 124
    cli();                                              // Menonaktifkan interupt ketika kondisi interupsi tercapai
    Signal = analogRead(signalPin);                     // Membaca Nilai ADC pin analog 0
    sampleCounter += 2;                                 // untuk menyimpan nterupsi yang telah dilakukan kenaikan setiap 2 ms
    int N = sampleCounter - lastBeatTime;               // digunakan untuk memonitor interval beat tunda sistem

    if(Signal < thres && N > (beatInterval/5)*3){       // waktu jeda untuk menghindari noise pada rentang beat interval
        if (Signal < Min){                              // T (trough)
            Min = Signal;                               // set batas terendah sinyal
        }
    }
      
    if(Signal > thres && Signal > Max){                
        Max = Signal;                                  // set batas tertinggi sinyal
       }                                   
       
  //------------------------------------------------------------>>>>Analisis Sinyal Detak<<<<-------------------------------------------------------------
  if (N > 270){                                             // waktu rentang yang diambil untuk menghindari noise antar detak dengan asumsi detak terbanyak 220 bpm 
    if ( (Signal > thres) && (pulseArea == false) && (N > (beatInterval/5)*3) ){        
        pulseArea = true;                                   // bernilai benar ketika berada pada area yang diperkirakan terjadi detak janting
        digitalWrite(ledPin,HIGH);                          // Led pin 13 hidup
        digitalWrite(buzzPin,HIGH); 
        beatInterval = sampleCounter - lastBeatTime;        // menghitung waktu antar detak
        lastBeatTime = sampleCounter;                      
        
        if(firstBeat){                                      // bernilai benar ketika detak pertama ditemukan
             firstBeat = false;                             // reset flag
             return;                                        
        }   
        if(secondBeat){                                     // bernilai benar ketika detak kedua ditemukan
            secondBeat = false;                             // reset flag
              for(int i=0; i<=9; i++){                      // menyimpan beat interval pada array untuk dicari nilai rata-rata
                   temp[i] = beatInterval;                      
              }
        }
    word runningTotal = 0;               
    for(int i=0; i<=8; i++){                // menggeser data pada array
         temp[i] = temp[i+1];               // menghapus data beat terlama 
         runningTotal += temp[i];           // menjumlahkan 9 data beat lama kedalam variabel runningTotal
    }
    
    temp[9] = beatInterval;                 // menambahkan data beat terbaru pada array terakhir
    runningTotal += temp[9];                // menambahkan data beat terbaru pada runningTotal
    runningTotal /= 10;                     // merata-rata beat interval
    BPM = 60000/runningTotal;               // mendapatkan nilai BPM
    findBeat = true;                        // set flag untuk menandakan bahwa beat ditemukan 
    }                       
  }

  if (Signal < thres && pulseArea == true){    //Ketika signal melemah dan masih berada pada area perkiraa detak (pulseArea == true)
      digitalWrite(ledPin,LOW);                //Led pin 13 (on Boadr led) dimatikan
      digitalWrite(buzzPin,LOW);
      pulseArea = false;                       //Diasumsikan bahwasanya ketika sinyal melemah, analisis sudah berada diluar area detak
      Amp = Max - Min;                         //Mencari nilai amplitudo
      thres = Amp/2 + Min;                     //Update nilai tres (treshold) 
      Max = thres;                             //Reset Min Max untuk menyesuaikan dengan nilai maksimum dan minimum detak yang baru (sistem dinamis)
      Min = thres;
  }
  
  if (N > 2500){                              // Jika N melebihi nilai 25000 (2.5 detik) berarti pendeteksian gagal karena nilai N terus melakukan increment
      thres = 415;                            // set thresh default
      Max = 415;                              // set Max ke nilai awal
      Min = 415;                              // set Min ke nilai awal
      lastBeatTime = sampleCounter;           // Jangan biarkan sample counter increment terlalu jauh dan meninggalkan lastBeatTime tertinggal tanpa update walaupun detak tidak terdeteksi         
      firstBeat = true;                       // set flag untuk mendapatkan data realistis BPM
      secondBeat = true;                  
  }
  
  sei();                                 
}
